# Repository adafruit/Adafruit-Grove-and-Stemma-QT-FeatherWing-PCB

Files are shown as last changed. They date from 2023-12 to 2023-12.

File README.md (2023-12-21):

## Adafruit Grove and Stemma QT FeatherWing for all Feathers PCB

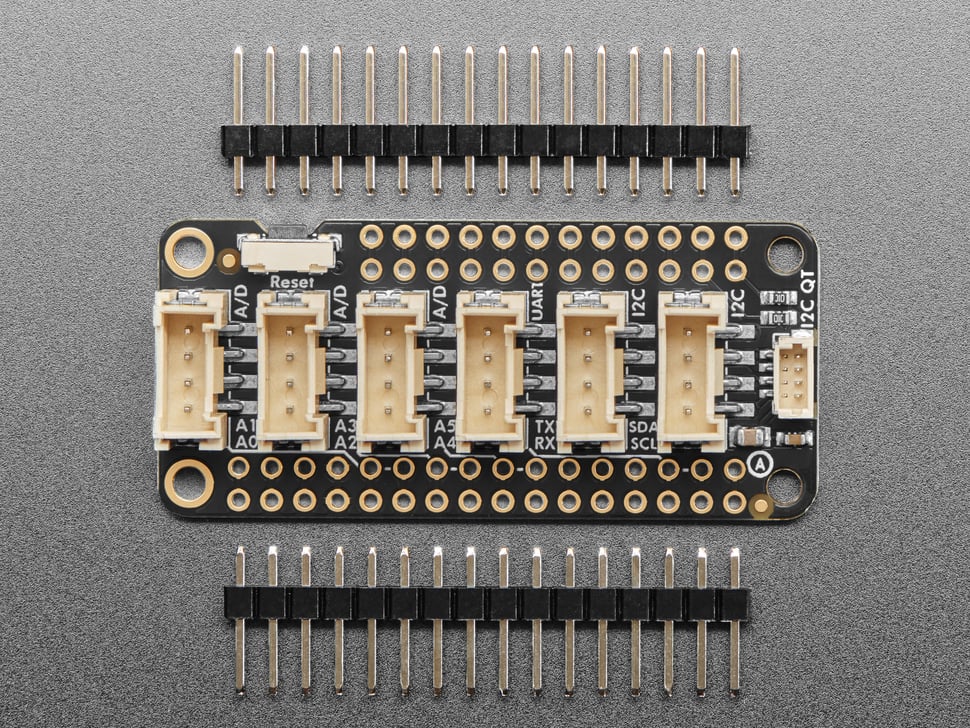
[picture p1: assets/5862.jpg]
<a href="http://www.adafruit.com/products/5862"><br/>
Click here to purchase one from the Adafruit shop</a>

PCB files for the Adafruit Grove and Stemma QT FeatherWing for all Feathers. 

Format is EagleCAD schematic and board layout
* https://www.adafruit.com/product/5862

### Description

The Adafruit Grove and Stemma QT FeatherWing for all Feathers allows folks to use many Grove devices with Feather boards! It fits nicely on top and has 3x Analog/Digital connectors, 1x UART connector and 2x I2C connectors. Not a ton, but enough to get many small projects going! We even managed to fit a vertical Stemma QT port on the end for another I2C connection.

Grove is a plug-and-play system from Seeed that features a 4-pin 2mm pitch connector (that is not JST PH). One thing to note is that the same connector is used for analog, digital, I2C, PWM, or UART: power, ground and two signals. So before plugging in a Grove sensor please make sure that you have the right 'matching' port: UART Groves should only go into UART port. I2C Groves go only into the I2C ports. Also, not every Feather has 6 Analog inputs, for example the RP2040 Feathers have only 4, or have hardware UART that's available for peripheirals, like the ESP8266 - so be aware of the underlying Feather boards' capabilites!

Comes with an assembled FeatherWing and two pieces of 16-pin header. Some light soldering is required to attach the header so it can be plugged into your Feather or doubler.

### License

Adafruit invests time and resources providing this open source design, please support Adafruit and open-source hardware by purchasing products from [Adafruit](https://www.adafruit.com)!

Designed by Limor Fried/Ladyada for Adafruit Industries.

Creative Commons Attribution/Share-Alike, all text above must be included in any redistribution. 
See license.txt for additional details.

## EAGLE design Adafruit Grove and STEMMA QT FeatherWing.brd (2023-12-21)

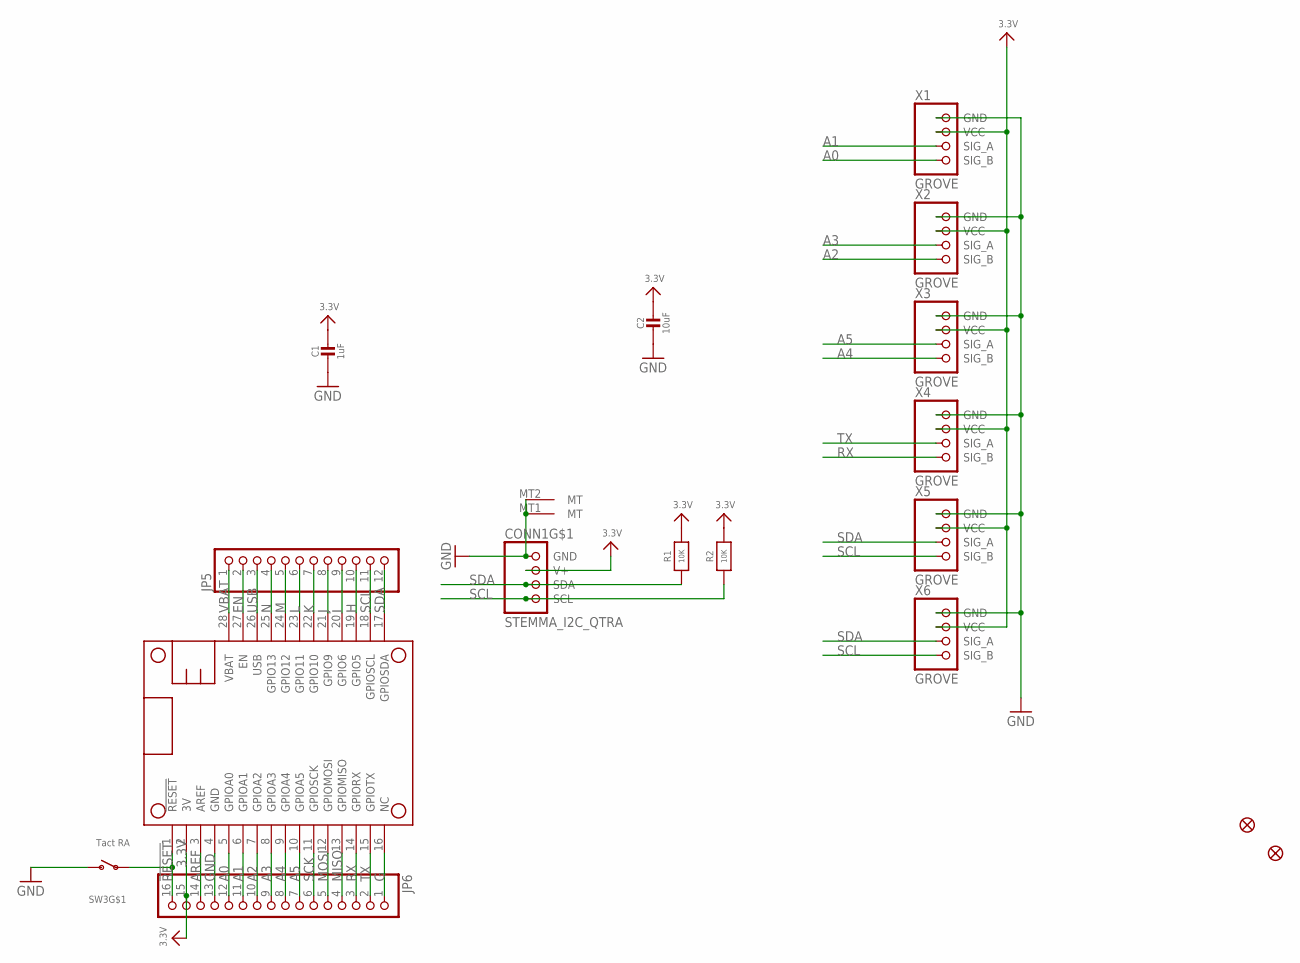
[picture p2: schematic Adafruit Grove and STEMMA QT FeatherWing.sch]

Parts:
C1: 1uF; 0603-NO
C2: 10uF; 0805-NO
CONN1: STEMMA_I2C_QTRA; JST_SH4_RA
FID1, FID2: FIDUCIAL_1MM
JP5: HEADER-1X12; 1X12_ROUND
JP6: HEADER-1X16ROUND; 1X16_ROUND
MS1: FEATHERWING_NODIM
R1, R2: 10K; 0603-NO
SW3: Tact RA; SPST_TACTILE_RA
X1, X2, X3, X4, X5, X6: GROVE; GROVE_SMTV

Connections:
3.3V: C1.1, C2.1, CONN1.2 (V+), JP6.15, MS1.2 (3V), R1.2, R2.2, X1.2 (VCC), X2.2 (VCC), X3.2 (VCC), X4.2 (VCC), X5.2 (VCC), X6.2 (VCC)
!RESET: JP6.16, MS1.1 (!RESET), SW3.1
A0: JP6.12, MS1.5 (GPIOA0), X1.4 (SIG_B)
A1: JP6.11, MS1.6 (GPIOA1), X1.3 (SIG_A)
A2: JP6.10, MS1.7 (GPIOA2), X2.4 (SIG_B)
A3: JP6.9, MS1.8 (GPIOA3), X2.3 (SIG_A)
A4: JP6.8, MS1.9 (GPIOA4), X3.4 (SIG_B)
A5: JP6.7, MS1.10 (GPIOA5), X3.3 (SIG_A)
AREF: JP6.14, MS1.3 (AREF)
EN: JP5.2, MS1.27 (EN)
G: JP6.1, MS1.16 (NC)
GND: C1.2, C2.2, CONN1.1 (GND), CONN1.MT1 (MT), CONN1.MT2 (MT), JP6.13, MS1.4 (GND), SW3.2 (S), X1.1 (GND), X1.MT1 (GND), X1.MT2 (GND), X2.1 (GND), X2.MT1 (GND), X2.MT2 (GND), X3.1 (GND), X3.MT1 (GND), X3.MT2 (GND), X4.1 (GND), X4.MT1 (GND), X4.MT2 (GND), X5.1 (GND), X5.MT1 (GND), X5.MT2 (GND), X6.1 (GND), X6.MT1 (GND), X6.MT2 (GND)
H: JP5.10, MS1.19 (GPIO5)
I: JP5.9, MS1.20 (GPIO6)
J: JP5.8, MS1.21 (GPIO9)
K: JP5.7, MS1.22 (GPIO10)
L: JP5.6, MS1.23 (GPIO11)
M: JP5.5, MS1.24 (GPIO12)
MISO: JP6.4, MS1.13 (GPIOMISO)
MOSI: JP6.5, MS1.12 (GPIOMOSI)
N: JP5.4, MS1.25 (GPIO13)
RX: JP6.3, MS1.14 (GPIORX), X4.4 (SIG_B)
SCK: JP6.6, MS1.11 (GPIOSCK)
SCL: CONN1.4 (SCL), JP5.11, MS1.18 (GPIOSCL), R2.1, X5.4 (SIG_B), X6.4 (SIG_B)
SDA: CONN1.3 (SDA), JP5.12, MS1.17 (GPIOSDA), R1.1, X5.3 (SIG_A), X6.3 (SIG_A)
TX: JP6.2, MS1.15 (GPIOTX), X4.3 (SIG_A)
USB: JP5.3, MS1.26 (USB)
VBAT: JP5.1, MS1.28 (VBAT)

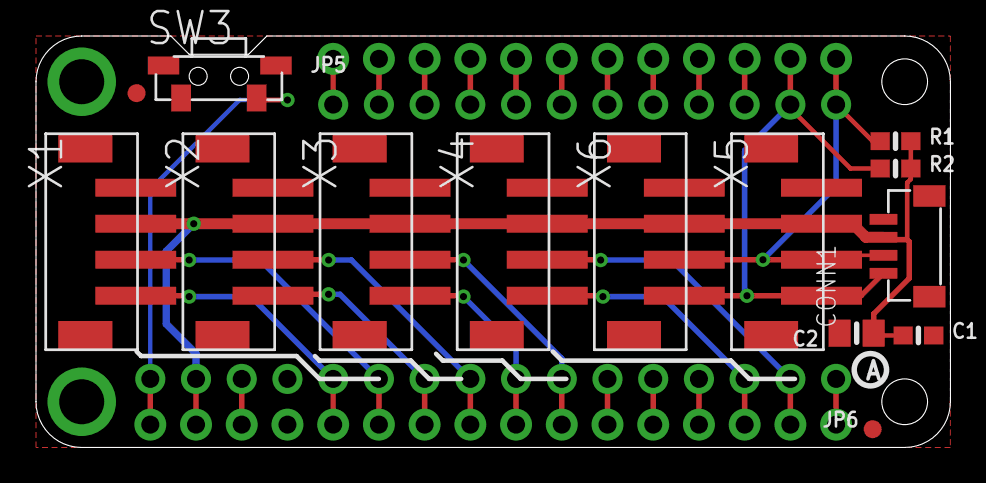
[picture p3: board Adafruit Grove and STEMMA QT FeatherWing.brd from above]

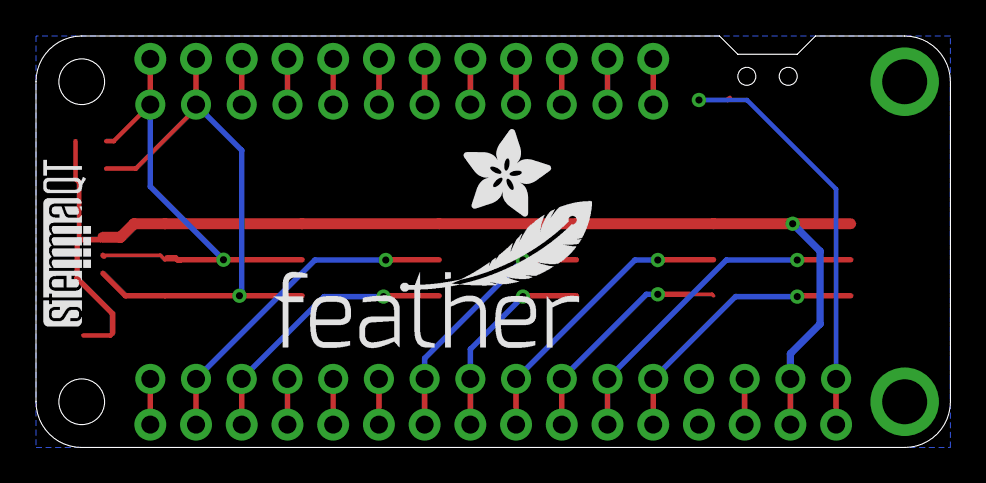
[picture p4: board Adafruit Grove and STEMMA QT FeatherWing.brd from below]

Board: 2 copper layers, 50.8 x 22.9 mm, 41 parts (5 on the bottom side), 28 nets.

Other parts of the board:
PLABEL0: PLABEL0
PLABEL1: PLABEL1
PLABEL2: PLABEL2
PLABEL3: PLABEL3
PLABEL4: PLABEL4
PLABEL5: PLABEL5
PLABEL6: PLABEL6
PLABEL7: PLABEL7
PLABEL8: PLABEL8
PLABEL9: PLABEL9
PLABEL10: PLABEL10
PLABEL11: PLABEL11
PLABEL12: PLABEL12
PLABEL13: PLABEL13
PLABEL14: PLABEL14
PLABEL15: PLABEL15
PLABEL16: PLABEL16
PLABEL17: PLABEL17
PLABEL18: PLABEL18
PLABEL19: PLABEL19
U$5: FEATHERLOGO_MED
U$7: ADAFRUIT_5MM
U$8: PCBFEAT-REV-040
U$11: STEMMAQT

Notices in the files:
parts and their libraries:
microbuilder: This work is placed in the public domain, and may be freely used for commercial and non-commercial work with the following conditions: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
